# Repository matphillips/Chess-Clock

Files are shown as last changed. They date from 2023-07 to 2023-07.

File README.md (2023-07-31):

# Chess-Clock

### ESP8266 powered Chess Clock.

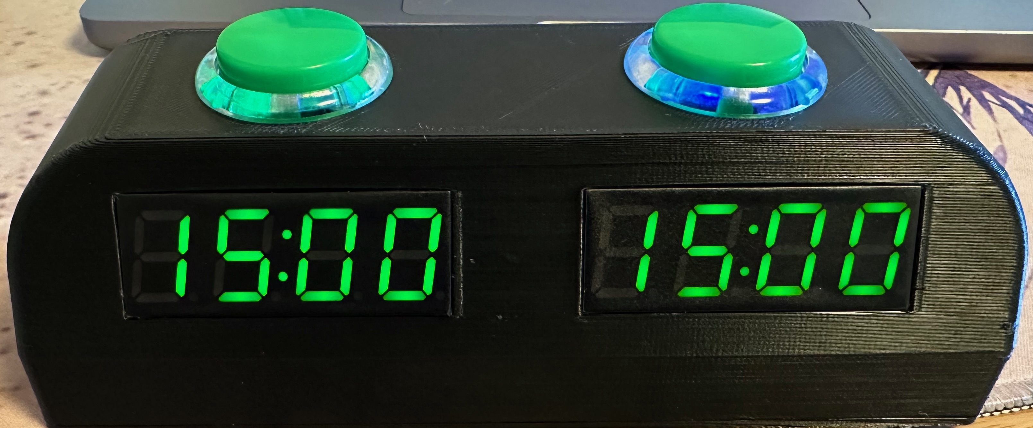
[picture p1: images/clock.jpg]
Chess Clock


#### Overview
Software is basic but functional. Mode button on the back to set the amount of time allocated to each player, and a brightness button on the back to set the brightness of the 7-segment displays.

Once the desired game time has been selected, hit either of the player buttons on the top of the clock to start the other players time counting down. If any player reaches zero seconds, their display flashes and a tone is sounded from the internal buzzer.

Pressing any player button when in 'game over' mode will reset the game. If the game is completed before the timer runs out, the only way to start a new game is to turn it off and back on. I'll probably add a reset function caused by pressing both player buttons at the same time, or some similar action.

#### Construction
The STL files are provided, I printed in PLA with 3 perimeters, 0.4mm nozzle, no supports. The print orientation of the files is correct. No supports are needed. There is a sacrificial bridge for the player button holes. Cut the hole clear with a sharp knife when print is finished.

Any ESP can probably be used, I had some ESP-12 modules laying around so I used that. All available IO is occupied, so there is no serial logging in the sketch, as the UART pins are being used for buttons.

Solder everything up according to the pin definitions in the sketch.

#### Parts
These links will probably not last, but these are most of the parts I used:

* **Play buttons:** https://www.aliexpress.com/item/32651573107.html (Arcade Push Button 30MM 24MM Game Switch Have Click Sound Microswitch PC /PS3 USB Joystick DIY SANWA OBSF Copy Replace)
* **mode & power buttons:** Standard 5mm tacswitch. Shorter one for the power button to avoid accidental presses.
* **Displays:** https://www.aliexpress.com/item/1005002059351703.html (TM1637 LED Display Module for Arduino 4 Digit 7 Segment 0.56 inch Time Clock Indicator Tube Module Red Blue Green Yellow White)
* **Battery charge unit:** https://www.aliexpress.com/item/1005003340733366.html (Type-C USB 5V 2A Boost Converter Step-Up Power Module Lithium Battery Charging Protection Board LED Display USB For DIY Charger)
* **3.3V regulator:** for beeper and esp8266
* **Beeper:** (3 pin style)
* **Battery:** I used a spare 18650 but anything will do.
* **Tinting film:** Cover the displays to increase contrast.
* **& Plenty of hot glue!**

Power button is connected to the charge control board. One click for on, two clicks for off. These charge boards are basically what is used in cheap 18650 power banks.

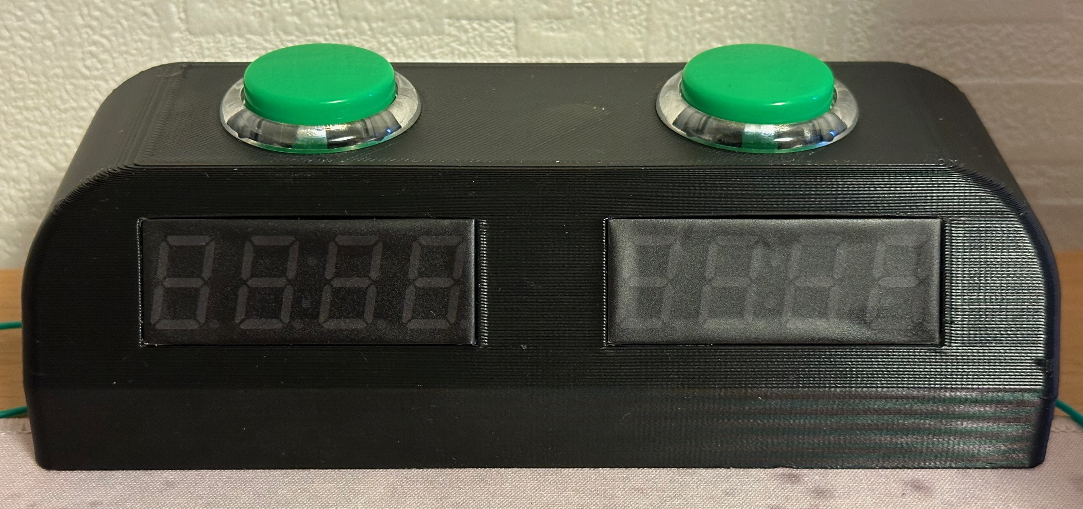
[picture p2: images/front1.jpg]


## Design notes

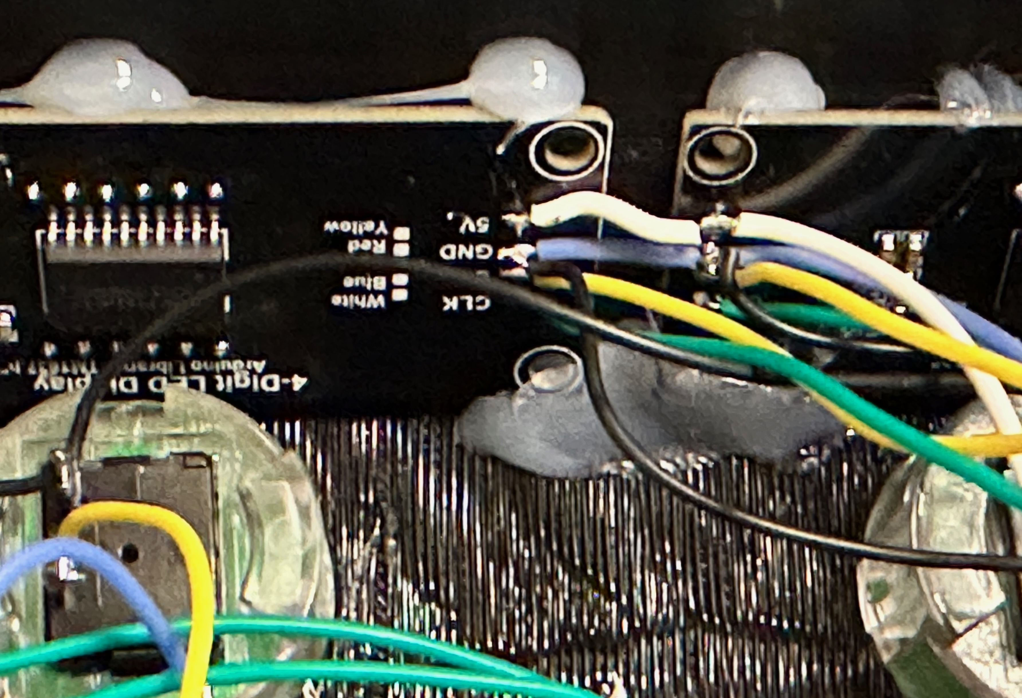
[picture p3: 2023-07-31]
images/inside2.jpg

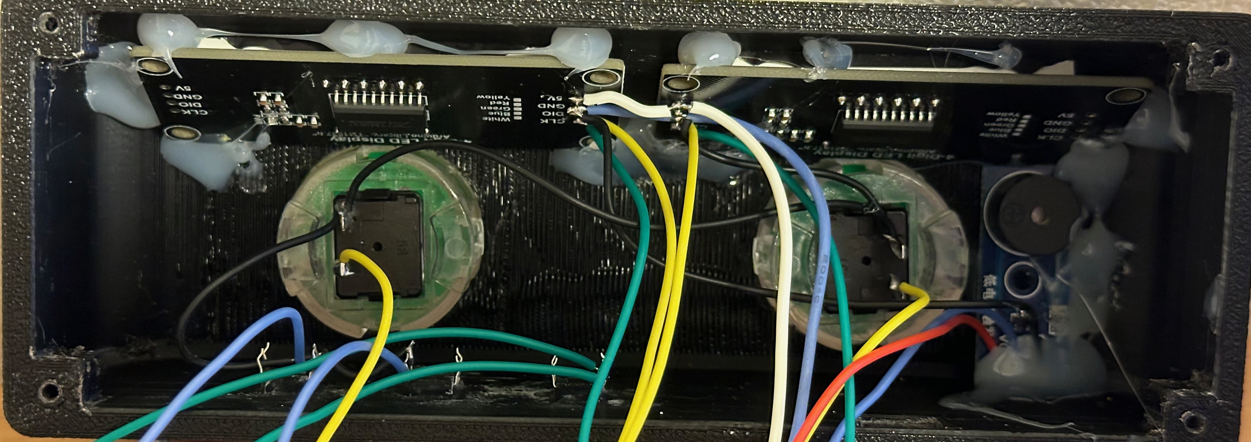
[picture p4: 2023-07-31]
images/inside1.jpg

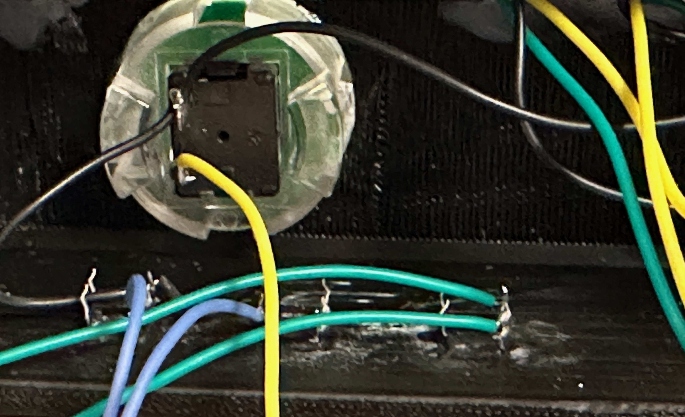
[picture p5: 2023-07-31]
images/inside3.jpg

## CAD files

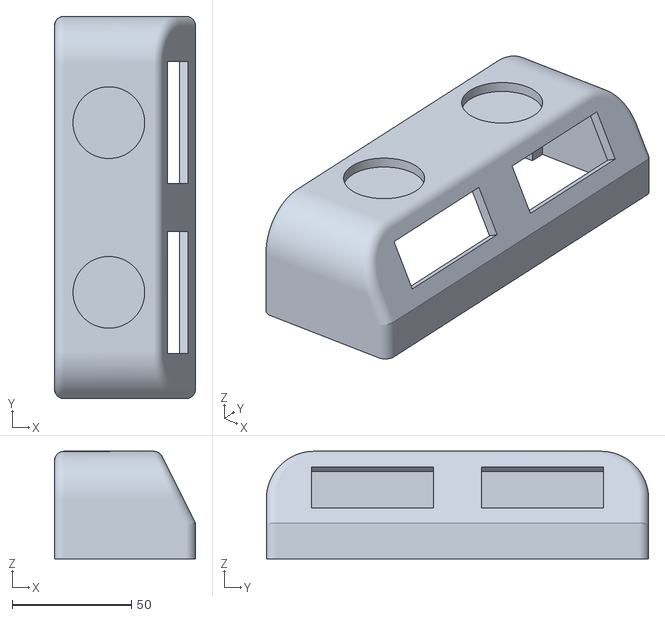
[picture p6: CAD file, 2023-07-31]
STL files/top.stl
59.0 x 160.0 x 45.0

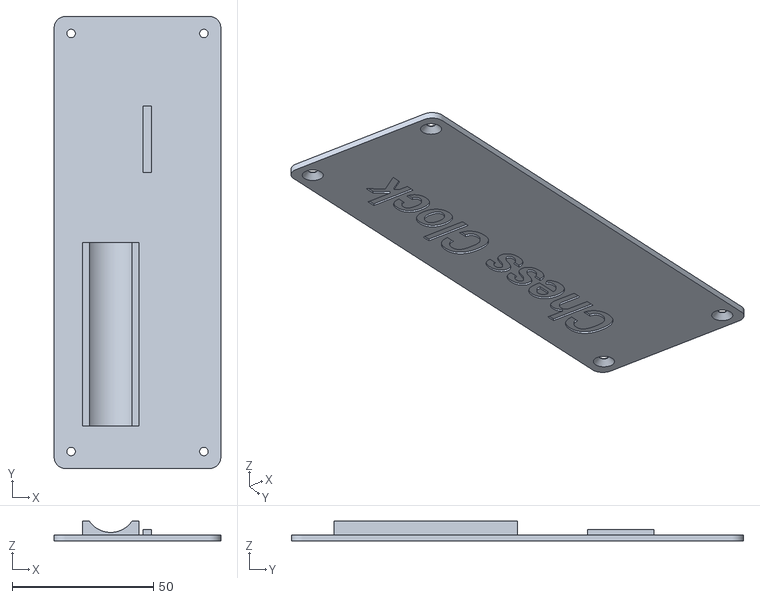
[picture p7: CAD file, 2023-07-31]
STL files/base.stl
59.0 x 160.0 x 7.00

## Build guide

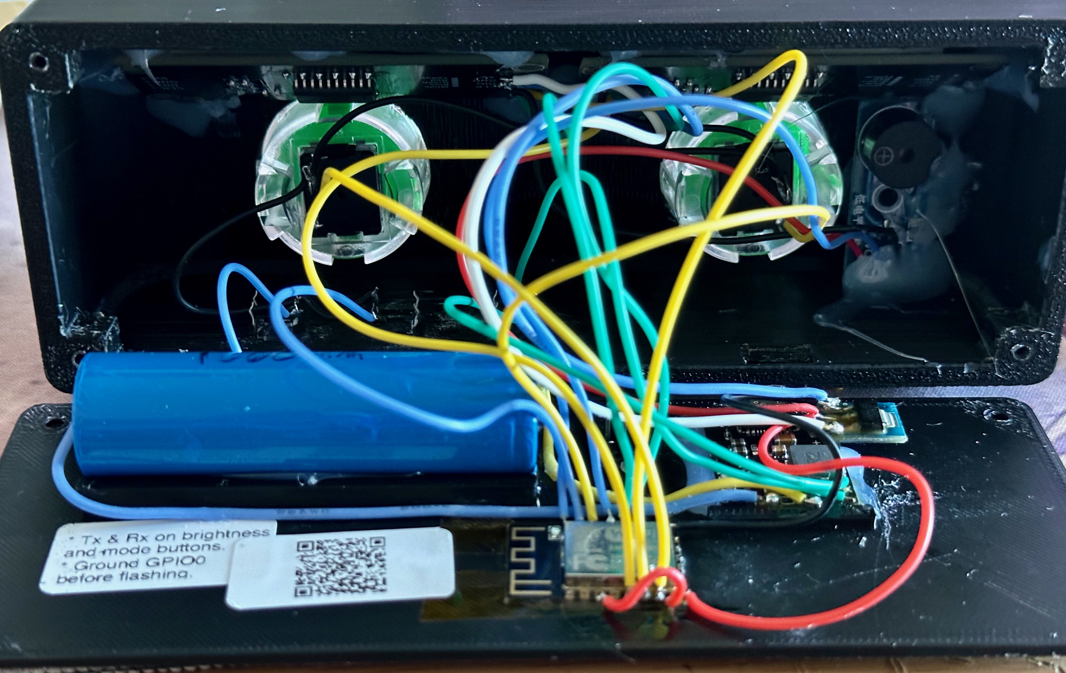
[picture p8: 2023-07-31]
images/wiringmess.jpg

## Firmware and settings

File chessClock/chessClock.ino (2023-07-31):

// Chess Clock. MPhillips. https://github.com/matphillips/Chess-Clock
//
#include <TM1637.h> // https://github.com/AKJ7/TM1637
#include <ESP8266WiFi.h>
#include "Buzzer.h" // https://github.com/gmarty2000-ARDUINO/arduino-BUZZER
#include <Button.h> // https://github.com/madleech/Button
#include <Ticker.h>

#define FPM_SLEEP_MAX_TIME 0xFFFFFFF
#define MAX_BRIGHTNESS_LEVELS 4
#define MAX_GAME_LENGTHS 5

// define pins
#define DIO1 12
#define CLK1 0 // 0
#define DIO2 14
#define CLK2 2
#define BUTTON_MODE 3 // 13
#define BUTTON_BRIGHTNESS 1
#define BUTTON_LEFT 13 // 4
#define BUTTON_RIGHT 5
#define BUZZER_PIN 4 // 3

// init
TM1637 display1(CLK1, DIO1);
TM1637 display2(CLK2, DIO2);
Buzzer buzzer(BUZZER_PIN);
Button buttonMode(BUTTON_MODE);
Button buttonBrightness(BUTTON_BRIGHTNESS);
Button buttonLeft(BUTTON_LEFT);
Button buttonRight(BUTTON_RIGHT);
Ticker tickerPlayer1;
Ticker tickerPlayer2;
Ticker tickerFlash;

// vars
int brightnessLevels[MAX_BRIGHTNESS_LEVELS] = {1, 2, 4, 9};
int brightness = 2;
int gameLengths[MAX_GAME_LENGTHS] = {5, 10, 15, 25, 40, 60};
int gameLength = 2;
int gameState = 0; // 0 not started, 1 running, 2 finished
int activePlayer = 0; // 0 not started, 1 left, 2 right
int player1time = 0;
int player2time = 0;
bool playedGameOverSound = false;
bool flashState = false;

// Vars to track elapsed time
unsigned long prevTimePlayer1 = 0;
unsigned long prevTimePlayer2 = 0;

void setup() {
  wifiOff();
  buttonMode.begin();
  buttonBrightness.begin();
  buttonLeft.begin();
  buttonRight.begin();
  tickerPlayer1.attach(1.0, tickerHandler);
  tickerPlayer2.attach(1.0, tickerHandler);
  tickerFlash.attach(0.5, tickerHandler);
  display1.init();
  display2.init();
  display1.setBrightness(brightnessLevels[brightness]);
  display2.setBrightness(brightnessLevels[brightness]);
  display1.colonOn();
  display2.colonOn();
  beepStartup();
}

void loop() {
  handleButtonPress();
  
  if (buttonMode.released() && gameState == 0) { // cycle game time mode
    gameLength = (gameLength == MAX_GAME_LENGTHS-1) ? 0 : gameLength + 1;
  }

  if (buttonBrightness.released()) { // cycle brightness levels
    brightness = (brightness == MAX_BRIGHTNESS_LEVELS-1) ? 0 : brightness + 1;
    display1.setBrightness(brightnessLevels[brightness]);
    display2.setBrightness(brightnessLevels[brightness]);
    display1.refresh();
    display2.refresh();
  }

  if (gameState == 1 && (player1time == 0 || player2time == 0)) { // player out of time, stop game
    gameState = 2;
  }

  switch (gameState) {
    case 0: // Idle, both clocks show max time
      display1.display(formatTime(gameLengths[gameLength]) + formatTime(0).c_str());
      display2.display(formatTime(gameLengths[gameLength]) + formatTime(0).c_str());
    break;

    case 1: // Running, clocks count down
      if (activePlayer == 1) {
        int minutes = player1time / 60; // Integer division to get the whole minutes
        int seconds = player1time % 60; // Remainder will be the seconds
        String timeStr = formatTime(minutes) + formatTime(seconds);
        display1.display(timeStr.c_str());
      }
      if (activePlayer == 2) {
        int minutes = player2time / 60; // Integer division to get the whole minutes
        int seconds = player2time % 60; // Remainder will be the seconds
        String timeStr = formatTime(minutes) + formatTime(seconds);
        display2.display(timeStr.c_str());
      }
    break;

    case 2: // game over
      if (!playedGameOverSound) {
        beepGameover();
        playedGameOverSound = true;
      }
    break;
  }
}

void resetGame() {
  playedGameOverSound = false;
  player1time = gameLengths[gameLength] * 60;
  player2time = gameLengths[gameLength] * 60;
  displayCountdownTime(display1, player1time);
  displayCountdownTime(display2, player2time);
  display1.colonOn();
  display2.colonOn();
  display1.refresh();
  display2.refresh();
}

void handleButtonPress() {
  bool isLeftButtonPressed = buttonLeft.released();
  bool isRightButtonPressed = buttonRight.released();

  if (isLeftButtonPressed || isRightButtonPressed) {
    if (gameState == 0) { // start game
      gameState = 1;
      resetGame();
      beepGameStart();
      activePlayer = (isLeftButtonPressed) ? 2 : 1;
    } else if (gameState == 1 && isLeftButtonPressed && activePlayer == 1) { // switch to other player
      activePlayer = 2;
      display1.colonOn();
      display1.refresh();
      beep();
    } else if (gameState == 1 && isRightButtonPressed && activePlayer == 2) { // switch to other player
      activePlayer = 1;
      display2.colonOn();
      display2.refresh();
      beep();
    } else if (gameState == 2) { // reset game
      gameState = 0;
      resetGame();
    }
  }
}

void displayCountdownTime(TM1637& display, int time) {
  int minutes = time / 60;
  int seconds = time % 60;
  String timeStr = formatTime(minutes) + formatTime(seconds);
  display.display(timeStr.c_str());
}

void tickerHandler() {
  unsigned long currentTime = millis();

  if (tickerPlayer1.active() && gameState == 1 && activePlayer == 1 && player1time > 0) {
    // Calculate elapsed time and update player1time
    if (currentTime - prevTimePlayer1 >= 1000) {
      prevTimePlayer1 = currentTime;
      player1time--;
    }
  }

  if (tickerPlayer2.active() && gameState == 1 && activePlayer == 2 && player2time > 0) {
    // Calculate elapsed time and update player2time
    if (currentTime - prevTimePlayer2 >= 1000) {
      prevTimePlayer2 = currentTime;
      player2time--;
    }
  }

  if (tickerFlash.active() && gameState == 1) {
    if (activePlayer == 1 && player1time > 0) {
      display1.switchColon();
      display1.refresh();
    }
    if (activePlayer == 2 && player2time > 0) {
      display2.switchColon();
      display2.refresh();
    }
  }

  if (tickerFlash.active() && gameState == 2) {
    if (player1time == 0) {
      display1.display((flashState) ? "0000" : "----");
      display1.colonOn();
    } else if (player2time == 0) {
      display2.display((flashState) ? "0000" : "----");
      display2.colonOn();
    }
    flashState = !flashState;
  }
}

String formatTime(int timeValue) { // Function to format time with leading zeros
  if (timeValue < 10) {
    return "0" + String(timeValue);
  } else {
    return String(timeValue);
  }
}

void beep() {
  buzzer.begin(0);
  buzzer.sound(NOTE_A5, 50);
  buzzer.end(10);
}

void beepStartup() {
  buzzer.begin(0);
  buzzer.sound(NOTE_A3, 100);
  buzzer.sound(NOTE_A4, 100);
  buzzer.sound(NOTE_A5, 100);
  buzzer.end(10);
}

void beepGameStart() {
  buzzer.begin(0);
  buzzer.sound(NOTE_A5, 90);
  buzzer.sound(NOTE_A6, 90);
  buzzer.sound(NOTE_A5, 90);
  buzzer.end(10);
}

void beepGameover() {
  buzzer.begin(0);
  buzzer.sound(NOTE_A5, 100);
  buzzer.sound(NOTE_A4, 100);
  buzzer.sound(NOTE_A3, 100);
  buzzer.sound(NOTE_A2, 100);
  buzzer.end(10);
}

void wifiOff() {
  wifi_station_disconnect();
  wifi_set_opmode(NULL_MODE);
  wifi_set_sleep_type(MODEM_SLEEP_T);
  wifi_fpm_open();
  wifi_fpm_do_sleep(FPM_SLEEP_MAX_TIME);
}
